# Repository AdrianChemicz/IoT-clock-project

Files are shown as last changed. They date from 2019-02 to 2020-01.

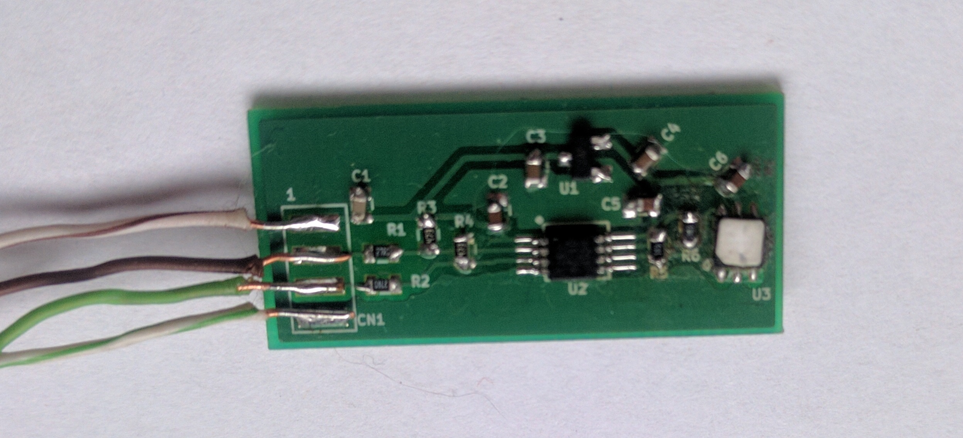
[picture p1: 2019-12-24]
clock_Pcb_schematic/clock_temperature_board/rev_1_0/clock_temperature_board_photo.jpg

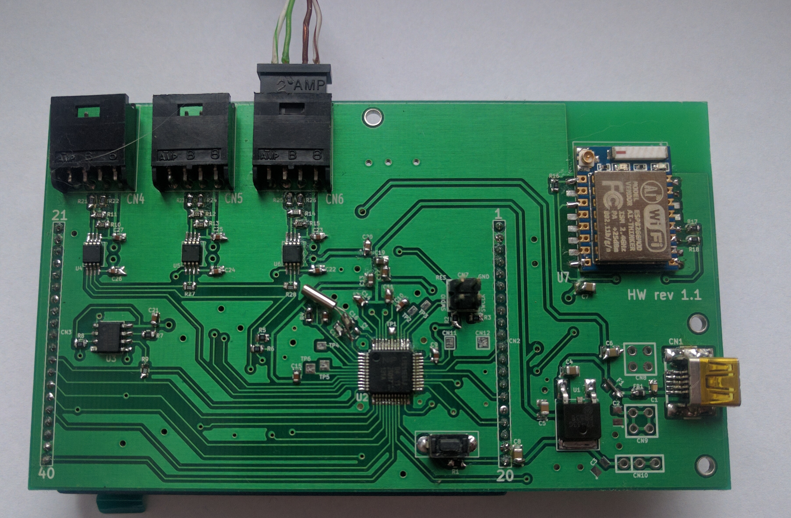
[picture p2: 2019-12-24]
clock_Pcb_schematic/clock_main_board/rev_1_1/clock_main_board_photo_bottom.jpg

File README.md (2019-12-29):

# IoT-clock-project
Concept:
Main idea behind project was create device which will gather 
temperature data from three sensors and display it on LCD. Selected
temperature source value will be stored in FRAM memory. 

Device will be used also as clock so near temperature on main 
window will be display curent hour. Device will be use WiFi 
interface to data synchronization(time and temperature measurement). 

Project phases:
1. I created PC driver which use FTDI chips and emulate interfaces of 
microntroller like GPIO, I2C, SPI and UART. I chosed LPC111X as target
microcontroller. I planed build final project on LPC1115 microcontroller.

2. Using emulated microcontroller interfaces I wrote drivers for LCD 
with ILI9325 controller, driver for touch screen with ADS7843 controller,
Si7021-A20 temperature sensor and ESP-01 module.

3) I created clock project with uGui library with first concept of 
application GUI. during development windows sdl library was used to 
display GUI. On final step of this phase test with real LCD was
performed and project work correctly.

4) I prepared code to run on real hardware (lpcxpresso board with 
LPC1114. Unfortunetly code exceed microcontroller flash limit. 
Code was modified to flash microcontroller and check basic 
functionality. After flashed all things work correctly. New 
microcontroller was chose to fulfil memory requirements it was 
LPC11E68. Evaluation board with this microcontroler was performed. 
Driver was ported to new microcontroller and all things work without
problem.

5) I prepared first release of clock board pcb with necessary
thing. Clock board contain FRAM (FM25W256), three I2C expander 
bus(PCA9507), footprint for ESP-07. The same code from my eval 
board run without any problem on clock board.

6) FRAM driver was added and store clockstate and temperature.
GUI functionality was added: set backlight of LCD, calibrate touch 
screen, factory reset, display temperature graph, calendar 
functionality, alarm animation. WiFi GUI concept was added.
uGui lobrary was modified to run faster.

First release of source code

7) WiFi support was be added. 

Second release of code.

8) New version of hardware with fixes.

9) Added support to monochrome bitmap in uGui. Added monochrome bitmap 
in GUI code. Added Options fields in bitmap.

Release of code with additional GUI thing.
First official release of HW.

10) Code refactoring is necessary to delete thing which isn't necessary 
and improve code readability.

Third release of code.

    -current place in project status-

11) Prepare housing for clock.
12) Prepare android application to control clock via Wifi.
13) Prepare document with clock specification.
14) Fix known issues:
	-change day should cause change data in time structure
	-fast switch between two temperature window cause issue with FRAM loading
	-load display temperature should load temperature even if gap will detected

License of code project:
  Below drivers is licensed under BSD 3-claus license:
  -BacklightControl
  -BuzzerControl
  -ESP_Layer
  -FRAM_Driver
  -GPIO_Driver
  -I2C_Driver
  -LCD
  -SOMEIP_Layer
  -SPI_Driver
  -TemperatureSensor
  -TouchPanel
  -UART_Driver
  
  Below files is licensed under GPL license:
  -ClockControl
  -GUI_Clock
  -Thread
  -WIFI_InteractionLayer

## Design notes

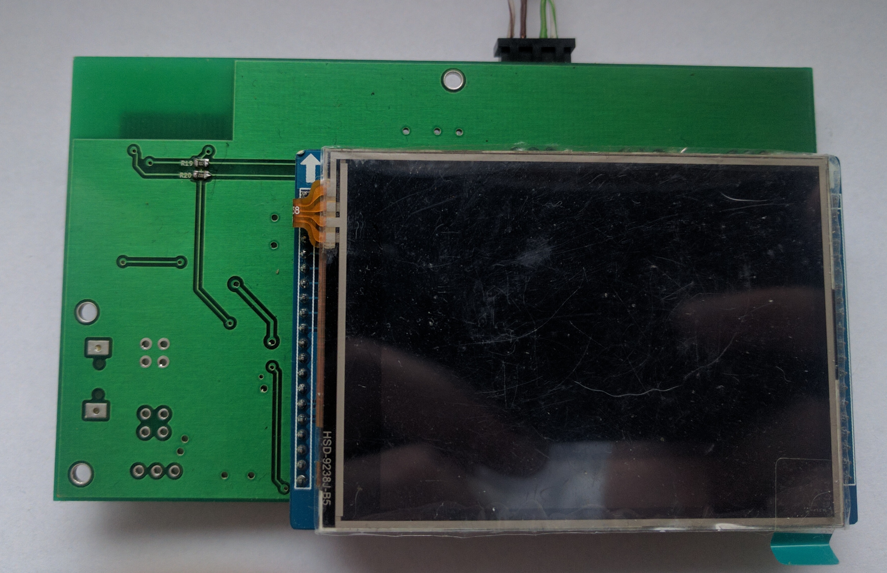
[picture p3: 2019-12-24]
clock_Pcb_schematic/clock_main_board/rev_1_1/clock_main_board_photo_upper.jpg

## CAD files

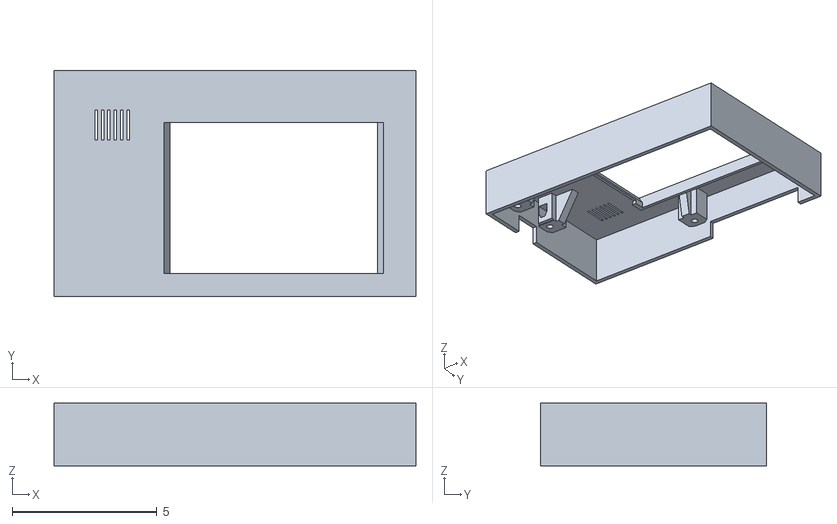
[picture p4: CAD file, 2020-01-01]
housing_stl_and_blender_files/ver_1_0/STL_Files/ClockHousing_UpperPart.stl
12.5 x 7.80 x 2.17

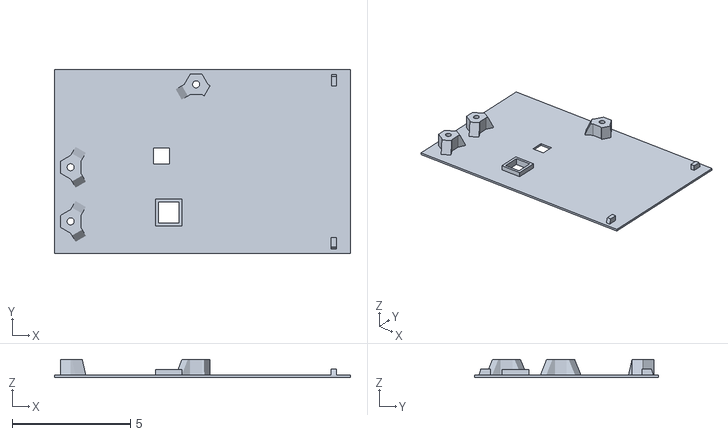
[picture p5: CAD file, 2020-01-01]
housing_stl_and_blender_files/ver_1_0/STL_Files/ClockHousing_BottomPart.stl
12.5 x 7.78 x 0.765

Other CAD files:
housing_stl_and_blender_files/ver_1_0/ClockHousing.blend
housing_stl_and_blender_files/ver_1_0/ClockHousing_AllStepsToCreate.blend
housing_stl_and_blender_files/ver_1_0/ClockHousing_BottomPart.blend
housing_stl_and_blender_files/ver_1_0/ClockHousing_UpperPart.blend
housing_stl_and_blender_files/ver_1_0/ClockPcb.blend
housing_stl_and_blender_files/ver_1_0/ClockPcb_AllStepsToCreate.blend

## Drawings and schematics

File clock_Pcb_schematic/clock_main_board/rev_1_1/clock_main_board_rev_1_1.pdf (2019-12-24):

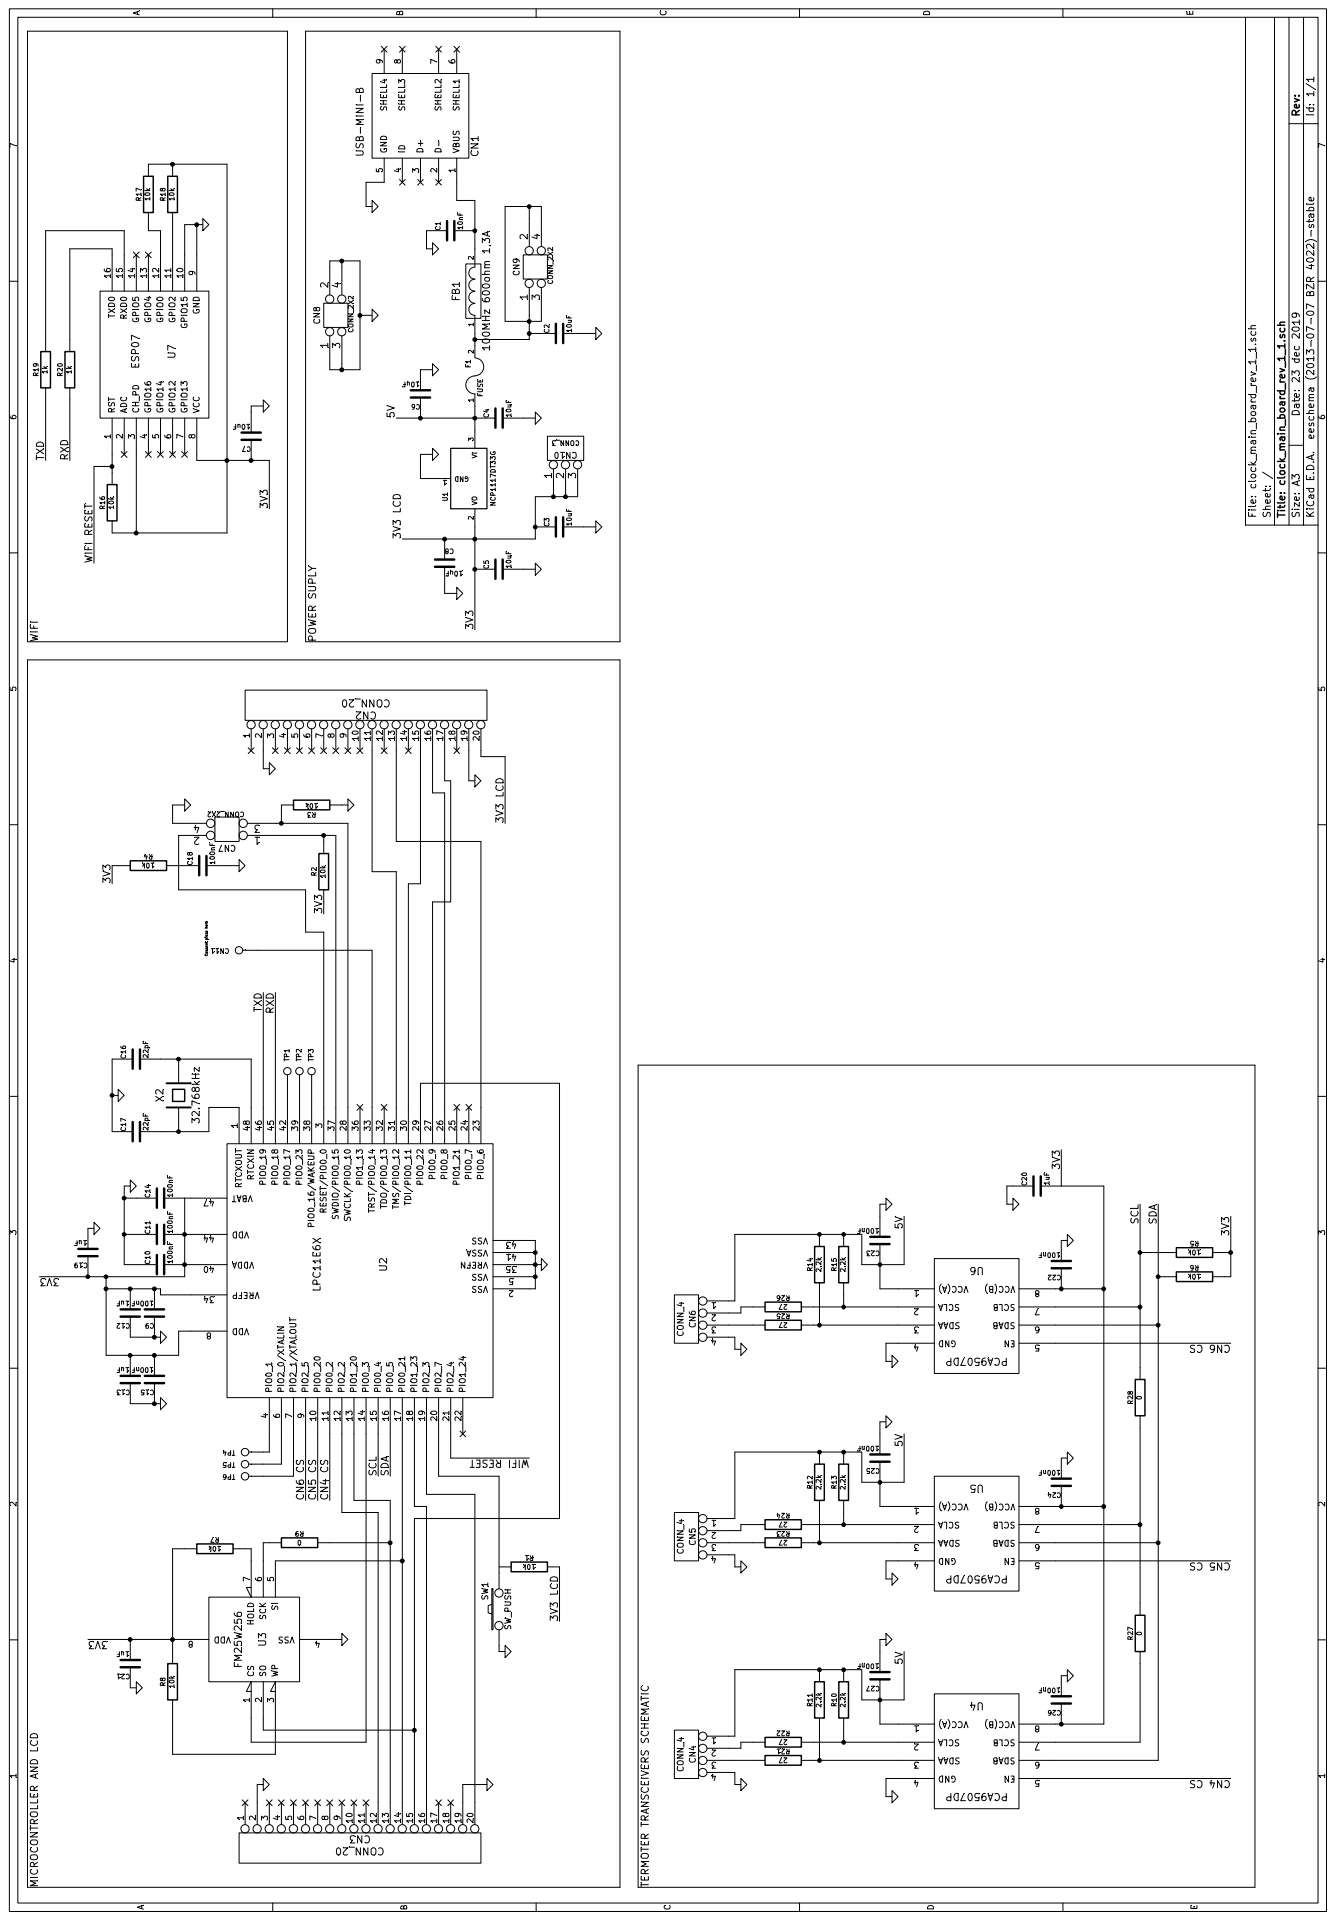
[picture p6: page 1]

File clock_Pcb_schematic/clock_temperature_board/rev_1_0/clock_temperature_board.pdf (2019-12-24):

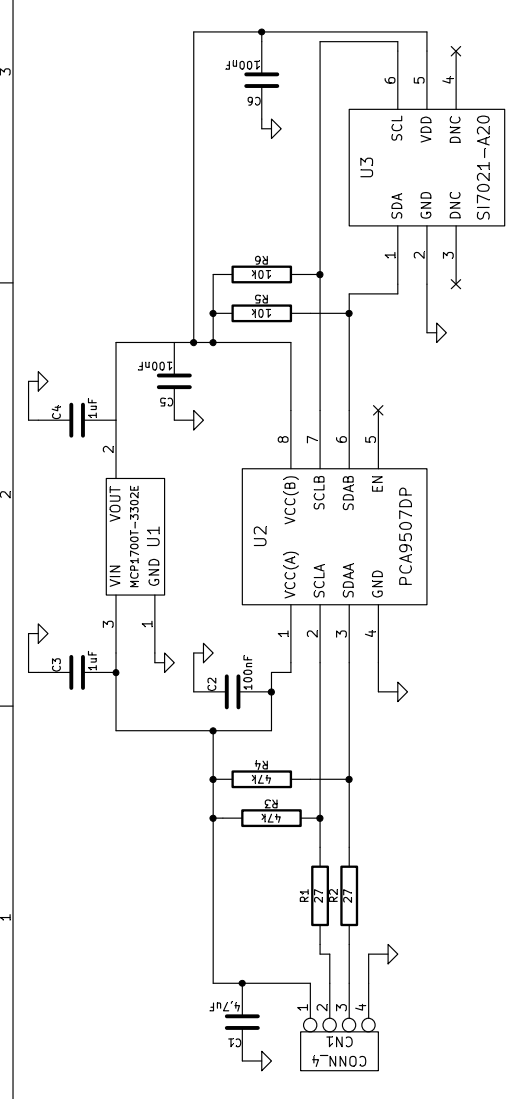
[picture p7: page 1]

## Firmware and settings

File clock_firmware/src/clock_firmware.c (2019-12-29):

/*

clock_firmware
Copyright (C) 2019 Adrian Chemicz

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
You should have received a copy of the GNU General Public License
along with this program. If not, see <http://www.gnu.org/licenses/>. */

#ifdef __USE_CMSIS
#include "chip.h"
#endif

#include "GPIO_Driver.h"
#include "SPI_Driver.h"
#include "UART_Driver.h"
#include "I2C_Driver.h"
#include "TouchPanel.h"
#include "GUI_Clock.h"
#include "TemperatureSensor.h"
#include "BacklightControl.h"
#include "BuzzerControl.h"
#include "FRAM_Driver.h"
#include "Thread.h"
#include "ClockControl.h"
#include "ESP_Layer.h"
#include "LCD.h"

#include <stdint.h>
#include <cr_section_macros.h>

int main(void)
{
	/**********************************
	*	initialize section
	***********************************/
	ClockChangeFrequency();

	//init touch mode
	TouchPanel_Init(1);

	//init GPIO port
	GPIO_Init();

	//init real LCD
	LCD_Init(0);

	FRAM_Init(1);

	//init backlight parameter
	Backlight_Init();

	Buzzer_Init();

	Chip_CRC_Init();

	//init bus for thermal sensors
	I2C_DriverInit(0);

	//init GPIO for manage I2C transceiver
	TemperatureSensor_Init();

	ESP_Init(0, 115200, 400, 3, 0);

	UART_DisableInterrupts(ESP_GetUartPortNumber());

	//search structure data in FRAM memory - two valid block is stored.
	if(ClockStateLoader(FRAM_CLOCK_STATE_FIRST_COPY))
	{

	}
	else if(ClockStateLoader(FRAM_CLOCK_STATE_SECOND_COPY))
	{

	}
	else//if all block is invalid then clear structure and init clock again
	{
		memset(&ClockState, 0, sizeof(ClockState));

		//set default brightness value
		ClockState.brightness = 80;

		//get calibration parameter for LCD
		ClockInitTouchScreen();

		//set default parameter for calendar - this parameter will be interpret as __ - __ - ____
		ClockState.day = INVALID_CALENDAR_DATE;
		ClockState.month = INVALID_CALENDAR_DATE;
		ClockState.year = INVALID_CALENDAR_DATE;

		//initialize FRAM index of all temperature sources
		ClockState.TemperatureSensorTable[INSIDE_TEMPERATURE].temperatureFramIndex = NOT_INITIALIZED_FRAM_INDEX_VALUE;
		ClockState.TemperatureSensorTable[OUTSIDE_TEMPERATURE].temperatureFramIndex = NOT_INITIALIZED_FRAM_INDEX_VALUE;
		ClockState.TemperatureSensorTable[FURNACE_TEMPERATURE].temperatureFramIndex = NOT_INITIALIZED_FRAM_INDEX_VALUE;
	}

	//set brightness
	Backlight_SetBrightness(ClockState.brightness);

	//calibrate LCD
	TouchPanel_SetCalibrationParameter(ClockState.x1RawCalibrationValue, ClockState.x2RawCalibrationValue,
		ClockState.y1RawCalibrationValue, ClockState.y2RawCalibrationValue);

	//clear fields which state must be checked again in new lifecycle
	ClockState.sharedSpiState = NOT_USED;
	ClockState.FramTransactionIdentifier = 0;

	//fields responsible for temperature
	ClockState.TemperatureSensorTable[INSIDE_TEMPERATURE].temperatureValue = INVALID_READ_SENSOR_VALUE;
	ClockState.TemperatureSensorTable[INSIDE_TEMPERATURE].temperatureValid = false;

	ClockState.TemperatureSensorTable[OUTSIDE_TEMPERATURE].temperatureValue = INVALID_READ_SENSOR_VALUE;
	ClockState.TemperatureSensorTable[OUTSIDE_TEMPERATURE].temperatureValid = false;

	ClockState.TemperatureSensorTable[FURNACE_TEMPERATURE].temperatureValue = INVALID_READ_SENSOR_VALUE;
	ClockState.TemperatureSensorTable[FURNACE_TEMPERATURE].temperatureValid = false;

	ClockState.refreshTemperatureValues = false;

	//clear fields responsible for raise allarm
	ClockState.firstAlarmRaised = false;
	ClockState.secondAlarmRaised = false;
	ClockState.temperatureFurnaceAlarmRaised = false;

	//clear counter responsible for refresh GUI interface if touch wasn't detected during 10s
	ClockState.refreshGuiCounter = 0;

	ClockState.factoryResetViaGui = false;

	//clear WiFi flags and IP address
	ClockState.wifiReady = false;
	ClockState.wifiApnReceived = false;
	ClockState.wifiConnected = false;
	ClockState.wifiStartDisconnect = false;

	memset(ClockState.ipAddressAssignedToDevice, 0, IP_ADDRESS_BYTE_LENGTH);

	//init structures responsible for draw temperature
	for(int i = 0; i < READ_TEMP_FRAM_BUFFER_SIZE; i++)
	{
		ReadFramTempBufferTable[i].availabilityFlag = false;
		ReadFramTempBufferTable[i].framIndex = 0;
		ReadFramTempBufferTable[i].notExistFlag = false;

		if(i == (READ_TEMP_FRAM_BUFFER_SIZE - 1))
		{
			ReadFramTempBufferTable[i].pointerToNextElement = &ReadFramTempBufferTable[0];
			ReadFramTempBufferTable[i].pointerToPreviousElement = &ReadFramTempBufferTable[i - 1];
		}
		else if(i == 0)
		{
			ReadFramTempBufferTable[i].pointerToNextElement = &ReadFramTempBufferTable[i + 1];
			ReadFramTempBufferTable[i].pointerToPreviousElement = &ReadFramTempBufferTable[(READ_TEMP_FRAM_BUFFER_SIZE-1)];
		}
		else
		{
			ReadFramTempBufferTable[i].pointerToNextElement = &ReadFramTempBufferTable[i + 1];
			ReadFramTempBufferTable[i].pointerToPreviousElement = &ReadFramTempBufferTable[i - 1];
		}
	}

	GUI_ClockInit();

	Thread_Init();

	ClockInitRtc();

	/**********************************
	*	main loop
	***********************************/
	for(;;)
	{
		static bool touchPanelState = false;

		if(TouchPanel_Process())
		{
			touchPanelState = true;
			uint16_t xPixelPosition = TouchPanel_CalculatePixelX(TouchPanel_ReturnRawX());
			uint16_t yPixelPosition = TouchPanel_CalculatePixelY(TouchPanel_ReturnRawY());

#if 1		//draw point after touch for debug purpose
			UG_DrawFrame(xPixelPosition - 2, yPixelPosition - 2, xPixelPosition + 2, yPixelPosition + 2, 0);
#endif
			UG_TouchUpdate(TouchPanel_CalculatePixelX(TouchPanel_ReturnRawX()),
				TouchPanel_CalculatePixelY(TouchPanel_ReturnRawY()), TOUCH_STATE_PRESSED);

			GUI_UpdateTime();
			UG_Update();

			ClockState.refreshGuiCounter = 0;
		}

		if(touchPanelState && !TouchPanel_TouchState())
		{
			UG_TouchUpdate(-1, -1, TOUCH_STATE_RELEASED);
			UG_Update();
			UG_Update();
			touchPanelState = false;

			ClockState.refreshGuiCounter = 0;
		}

		if(ClockState.refreshTemperatureValues == REFRESH)
		{
			GUI_UpdateTemperature();
			ClockState.refreshTemperatureValues = REFRESH_PERFORMED;
		}

		if(ClockState.refreshGuiCounter >= 5*ONE_SECONDS)
		{
			GUI_UpdateTime();

			UG_Update();
			ClockState.refreshGuiCounter = 0;
		}

		GUI_ProcessTemperatureWindow();
		GUI_ProcessAlarmAnimation();
		GUI_RefreshWifiWindow();
	}/* for(;;) */

    return 0;
}

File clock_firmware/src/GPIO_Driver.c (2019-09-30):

/*
 * Copyright (c) 2018, 2019, Adrian Chemicz
 * All rights reserved.
 *
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
 * THIS SOFTWARE IS PROVIDED BY THE COPYRIGHT HOLDERS AND CONTRIBUTORS "AS IS" AND
 * ANY EXPRESS OR IMPLIED WARRANTIES, INCLUDING, BUT NOT LIMITED TO, THE IMPLIED
 * WARRANTIES OF MERCHANTABILITY AND FITNESS FOR A PARTICULAR PURPOSE ARE
 * DISCLAIMED. IN NO EVENT SHALL COPYRIGHT HOLDER BE LIABLE FOR ANY
 * DIRECT, INDIRECT, INCIDENTAL, SPECIAL, EXEMPLARY, OR CONSEQUENTIAL DAMAGES
 * (INCLUDING, BUT NOT LIMITED TO, PROCUREMENT OF SUBSTITUTE GOODS OR SERVICES;
 * LOSS OF USE, DATA, OR PROFITS; OR BUSINESS INTERRUPTION) HOWEVER CAUSED AND
 * ON ANY THEORY OF LIABILITY, WHETHER IN CONTRACT, STRICT LIABILITY, OR TORT
 * (INCLUDING NEGLIGENCE OR OTHERWISE) ARISING IN ANY WAY OUT OF THE USE OF THIS
 * SOFTWARE, EVEN IF ADVISED OF THE POSSIBILITY OF SUCH DAMAGE.
 */

#include "GPIO_Driver.h"

#if USE_LPC111x_SERIES
#include "LPC11xx.h"
#endif

#if USE_LPC11E6x_SERIES
#include "chip.h"
#endif

static uint32_t* GPIO_GetBaseAddress(uint8_t portNumber)
{
	uint32_t* basePointer = 0;
#if USE_LPC111x_SERIES
	switch(portNumber)
	{
	case 0:
		basePointer = (uint32_t*)LPC_GPIO0;
		break;
	case 1:
		basePointer = (uint32_t*)LPC_GPIO1;
		break;
	case 2:
		basePointer = (uint32_t*)LPC_GPIO2;
		break;
	case 3:
		basePointer = (uint32_t*)LPC_GPIO3;
		break;
	default:
		basePointer = 0;
		break;
	}
#endif

#if USE_LPC11E6x_SERIES
	return basePointer;
#endif
}

void GPIO_Init(void)
{
	//Defined by user
	//turn on options responsible for change GPIO purpose like UART, ADC or SPI
	LPC_SYSCON->SYSAHBCLKCTRL |= (1<<16);
	//LCD CS - PIO0_12
	LPC_IOCON->PIO0[12] = 1;
	//LCD_Reset - PIO0_11
	LPC_IOCON->PIO0[11] = 1;

	//TP3(Debug purpose) PIO0_16
	GPIO_Direction(0, 16, GPIO_DIR_OUTPUT);
}

void GPIO_Direction(uint8_t port, uint8_t pin, GPIO_DIRECTION dir)
{
#if USE_LPC111x_SERIES
	uint32_t tmpDir = LPC_GPIO0->DIR;
	uint32_t dirMask = ~(1<<pin);
	LPC_GPIO_TypeDef *GPIO_Port = (LPC_GPIO_TypeDef*)GPIO_GetBaseAddress(port);

	GPIO_Port->DIR = (tmpDir & dirMask)|(dir<<pin);
#endif

#if USE_LPC11E6x_SERIES
	uint32_t tmpDir = LPC_GPIO->DIR[port];
	uint32_t dirMask = ~(1<<pin);

	LPC_GPIO->DIR[port] = (tmpDir & dirMask)|(dir<<pin);
#endif
}

void GPIO_SetState(uint8_t port, uint8_t pin, bool state)
{
#if USE_LPC111x_SERIES
	LPC_GPIO_TypeDef *GPIO_Port = (LPC_GPIO_TypeDef*)GPIO_GetBaseAddress(port);
	GPIO_Port->MASKED_ACCESS[1<<pin] = (state<<pin);
#endif

#if USE_LPC11E6x_SERIES
	LPC_GPIO->B[port][pin] = state;
#endif
}

bool GPIO_GetState(uint8_t port, uint8_t pin)
{	
#if USE_LPC111x_SERIES
	LPC_GPIO_TypeDef *GPIO_Port = (LPC_GPIO_TypeDef*)GPIO_GetBaseAddress(port);
	return ((GPIO_Port->MASKED_ACCESS[1<<pin])>>pin);
#endif

#if USE_LPC11E6x_SERIES
	return LPC_GPIO->B[port][pin];
#endif
}

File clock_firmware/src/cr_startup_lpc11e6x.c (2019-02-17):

//*****************************************************************************
// LPC11E6x Microcontroller Startup code for use with LPCXpresso IDE
//
// Version : 140113
//*****************************************************************************
//
// Copyright(C) NXP Semiconductors, 2014
// All rights reserved.
//
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
// Permission to use, copy, modify, and distribute this software and its
// documentation is hereby granted, under NXP Semiconductors' and its
// licensor's relevant copyrights in the software, without fee, provided that it
// is used in conjunction with NXP Semiconductors microcontrollers.  This
// copyright, permission, and disclaimer notice must appear in all copies of
// this code.
//*****************************************************************************

#if defined (__cplusplus)
#ifdef __REDLIB__
#error Redlib does not support C++
#else
//*****************************************************************************
//
// The entry point for the C++ library startup
//
//*****************************************************************************
extern "C" {
    extern void __libc_init_array(void);
}
#endif
#endif

#define WEAK __attribute__ ((weak))
#define ALIAS(f) __attribute__ ((weak, alias (#f)))

//*****************************************************************************
#if defined (__cplusplus)
extern "C" {
#endif

//*****************************************************************************
#if defined (__USE_CMSIS) || defined (__USE_LPCOPEN)
// Declaration of external SystemInit function
extern void SystemInit(void);
#endif

// Patch the AEABI integer divide functions to use MCU's romdivide library
#ifdef __USE_ROMDIVIDE
// Location in memory that holds the address of the ROM Driver table
#define PTR_ROM_DRIVER_TABLE ((unsigned int *)(0x1FFF1FF8))
// Variables to store addresses of idiv and udiv functions within MCU ROM
unsigned int *pDivRom_idiv;
unsigned int *pDivRom_uidiv;
#endif

//*****************************************************************************
//
// Forward declaration of the default handlers. These are aliased.
// When the application defines a handler (with the same name), this will 
// automatically take precedence over these weak definitions
//
//*****************************************************************************
     void ResetISR(void);
WEAK void NMI_Handler(void);
WEAK void HardFault_Handler(void);
WEAK void SVC_Handler(void);
WEAK void PendSV_Handler(void);
WEAK void SysTick_Handler(void);
WEAK void IntDefaultHandler(void);
//*****************************************************************************
//
// Forward declaration of the specific IRQ handlers. These are aliased
// to the IntDefaultHandler, which is a 'forever' loop. When the application
// defines a handler (with the same name), this will automatically take
// precedence over these weak definitions
//
//*****************************************************************************
void PIN_INT0_IRQHandler (void) ALIAS(IntDefaultHandler);
void PIN_INT1_IRQHandler (void) ALIAS(IntDefaultHandler);
void PIN_INT2_IRQHandler (void) ALIAS(IntDefaultHandler);
void PIN_INT3_IRQHandler (void) ALIAS(IntDefaultHandler);
void PIN_INT4_IRQHandler (void) ALIAS(IntDefaultHandler);
void PIN_INT5_IRQHandler (void) ALIAS(IntDefaultHandler);
void PIN_INT6_IRQHandler (void) ALIAS(IntDefaultHandler);
void PIN_INT7_IRQHandler (void) ALIAS(IntDefaultHandler);
void GINT0_IRQHandler (void) ALIAS(IntDefaultHandler);
void GINT1_IRQHandler (void) ALIAS(IntDefaultHandler);
void I2C1_IRQHandler (void) ALIAS(IntDefaultHandler);
void USART1_4_IRQHandler (void) ALIAS(IntDefaultHandler);
void USART2_3_IRQHandler (void) ALIAS(IntDefaultHandler);
void SCT0_1_IRQHandler (void) ALIAS(IntDefaultHandler);
void SSP1_IRQHandler (void) ALIAS(IntDefaultHandler);
void I2C0_IRQHandler (void) ALIAS(IntDefaultHandler);
void TIMER16_0_IRQHandler (void) ALIAS(IntDefaultHandler);
void TIMER16_1_IRQHandler (void) ALIAS(IntDefaultHandler);
void TIMER32_0_IRQHandler (void) ALIAS(IntDefaultHandler);
void TIMER32_1_IRQHandler (void) ALIAS(IntDefaultHandler);
void SSP0_IRQHandler (void) ALIAS(IntDefaultHandler);
void USART0_IRQHandler (void) ALIAS(IntDefaultHandler);
void ADCA_IRQHandler (void) ALIAS(IntDefaultHandler);
void RTC_IRQHandler (void) ALIAS(IntDefaultHandler);
void BOD_WDT_IRQHandler (void) ALIAS(IntDefaultHandler);
void FMC_IRQHandler (void) ALIAS(IntDefaultHandler);
void DMA_IRQHandler (void) ALIAS(IntDefaultHandler);
void ADCB_IRQHandler (void) ALIAS(IntDefaultHandler);
void USBWakeup_IRQHandler (void) ALIAS(IntDefaultHandler);

//*****************************************************************************
// The entry point for the application.
// __main() is the entry point for redlib based applications
// main() is the entry point for newlib based applications
//*****************************************************************************
#if defined (__REDLIB__)
extern void __main(void);
#endif
extern int main(void);
//*****************************************************************************
//
// External declaration for the pointer to the stack top from the Linker Script
//
//*****************************************************************************
extern void _vStackTop(void);
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

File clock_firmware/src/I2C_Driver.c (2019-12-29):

/*
 * Copyright (c) 2018, 2019, Adrian Chemicz
 * All rights reserved.
 *
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
 * THIS SOFTWARE IS PROVIDED BY THE COPYRIGHT HOLDERS AND CONTRIBUTORS "AS IS" AND
 * ANY EXPRESS OR IMPLIED WARRANTIES, INCLUDING, BUT NOT LIMITED TO, THE IMPLIED
 * WARRANTIES OF MERCHANTABILITY AND FITNESS FOR A PARTICULAR PURPOSE ARE
 * DISCLAIMED. IN NO EVENT SHALL COPYRIGHT HOLDER BE LIABLE FOR ANY
 * DIRECT, INDIRECT, INCIDENTAL, SPECIAL, EXEMPLARY, OR CONSEQUENTIAL DAMAGES
 * (INCLUDING, BUT NOT LIMITED TO, PROCUREMENT OF SUBSTITUTE GOODS OR SERVICES;
 * LOSS OF USE, DATA, OR PROFITS; OR BUSINESS INTERRUPTION) HOWEVER CAUSED AND
 * ON ANY THEORY OF LIABILITY, WHETHER IN CONTRACT, STRICT LIABILITY, OR TORT
 * (INCLUDING NEGLIGENCE OR OTHERWISE) ARISING IN ANY WAY OUT OF THE USE OF THIS
 * SOFTWARE, EVEN IF ADVISED OF THE POSSIBILITY OF SUCH DAMAGE.
 */

#include "I2C_Driver.h"
#include "chip.h"

static uint16_t SCLL;
static uint16_t SCLH;

I2C_Device_Instance I2C_Device_Instance_Table[NUMBER_OF_I2C_PERIPHERALS];

static uint32_t* I2C_GetBaseAddress(uint8_t portNumber)
{
	uint32_t* basePointer = 0;
	switch(portNumber)
	{
	case 0:
		basePointer = (uint32_t*)LPC_I2C0;
		break;
	default:
		basePointer = 0;
		break;
	}

	return basePointer;
}

static void I2C_SetClockPrescalers(uint8_t portNumber)
{
	/*must be defined by user*/
	switch(portNumber)
	{
	case 0:
#if 0
		SCLL = 0x40;
		SCLH = 0x40;
#else
		SCLL = 0x80;
		SCLH = 0x80;
#endif

		break;
	default:
		SCLL = 0x40;
		SCLH = 0x40;
		break;
	}
}

void I2C_InterruptProccess(uint8_t portNumber)
{
	LPC_I2C_T *I2C_Port = (LPC_I2C_T*)I2C_GetBaseAddress(portNumber);
	uint8_t busStatus = I2C_Port->STAT;

	switch(busStatus)
	{
	case 0x08://call when start was send
		//change device status
		I2C_Device_Instance_Table[portNumber].deviceStatus = I2C_SENDING;
		//clear start bit (STAC - START flag Clear bit)
		I2C_Port->CONCLR = (1<<5);

		if(I2C_Device_Instance_Table[portNumber].dataToSend > 0)
		{
			I2C_Device_Instance_Table[portNumber].dataToSendStatus = 0;
			I2C_Port->DAT = I2C_Device_Instance_Table[portNumber].deviceAddress;
		}
		else if(I2C_Device_Instance_Table[portNumber].dataToRead > 0)
		{
			I2C_Device_Instance_Table[portNumber].dataToReadStatus = 0;
			I2C_Port->DAT = (I2C_Device_Instance_Table[portNumber].deviceAddress|1U);
		}

		break;

	case 0x10://call when repeated start was send
		//clear start bit (STAC - START flag Clear bit)
		I2C_Port->CONCLR = (1<<5);

		I2C_Device_Instance_Table[portNumber].dataToReadStatus = 0;
		I2C_Port->DAT = (I2C_Device_Instance_Table[portNumber].deviceAddress|1U);
		break;
	//send data
	case 0x18://call when device address was send and ACK was received
	case 0x20://call when device address was send and ACK wasn't received
	case 0x28://call when data was send and ACK was received
	case 0x30://call when data was send and ACK wasn't received
		//execute when all data was send
		if(I2C_Device_Instance_Table[portNumber].dataToSendStatus
				== I2C_Device_Instance_Table[portNumber].dataToSend)
		{
			//check read buffer
			if(I2C_Device_Instance_Table[portNumber].dataToRead > 0)
			{
				//send start bit (in control set register STA bit - START flag)
				I2C_Port->CONSET = (1<<5);
			}
			else//execute when read data isn't necessary
			{
				//send stop bit(set STO bit - STOP flag.)
				I2C_Port->CONSET = (1<<4);
				I2C_Device_Instance_Table[portNumber].deviceStatus = I2C_WAITING_FOR_DATA;
			}
		}
		else //send data
		{
			I2C_Port->DAT = I2C_Device_Instance_Table[portNumber].sendBuffer[I2C_Device_Instance_Table[portNumber].dataToSendStatus];
			I2C_Device_Instance_Table[portNumber].dataToSendStatus++;
		}
		break;

	case 0x40://call when address of device was send with ACK
	case 0x48://call when address of device was send without ACK
		//check how much read data is needed. If one then clear ACK bit
		if((I2C_Device_Instance_Table[portNumber].dataToRead - I2C_Device_Instance_Table[portNumber].dataToReadStatus) == 1)
			//in control clear register set AAC - Assert acknowledge Clear bit
			I2C_Port->CONCLR = (1<<2);
		else//then more than one then set ACK bit
			//in control set register set AA - Assert acknowledge flag
			I2C_Port->CONSET = (1<<2);
		break;

	case 0x50://data was received. ACK was returned
		//check how much read data is needed. If one then clear ACK bit
		if((I2C_Device_Instance_Table[portNumber].dataToRead - I2C_Device_Instance_Table[portNumber].dataToReadStatus - 1) == 1)
			//in control clear register set AAC - Assert acknowledge Clear bit
			I2C_Port->CONCLR = (1<<2);
		else//then more than one then set ACK bit
			//in control set register set AA - Assert acknowledge flag
			I2C_Port->CONSET = (1<<2);

		I2C_Device_Instance_Table[portNumber].readBuffer[I2C_Device_Instance_Table[portNumber].dataToReadStatus] = I2C_Port->DAT;
		I2C_Device_Instance_Table[portNumber].dataToReadStatus++;
		break;

	case 0x58://data was received and ACK wasn't returned
		I2C_Device_Instance_Table[portNumber].readBuffer[I2C_Device_Instance_Table[portNumber].dataToReadStatus] = I2C_Port->DAT;
		I2C_Device_Instance_Table[portNumber].dataToReadStatus++;
		//in control set register set STOP flag
		I2C_Port->CONSET = (1<<4);

		I2C_Device_Instance_Table[portNumber].deviceStatus = I2C_WAITING_FOR_DATA;
		break;
	}
	//clear interrupt bit (SIC - I2C interrupt Clear bit)
	I2C_Port->CONCLR = (1<<3);
}

void I2C0_IRQHandler()
{
	I2C_InterruptProccess((uint8_t)0);
}

void I2C_DriverInit(uint8_t portNumber)
{
	LPC_I2C_T *I2C_Port = (LPC_I2C_T*)I2C_GetBaseAddress(portNumber);
	I2C_SetClockPrescalers(portNumber);

	I2C_Device_Instance_Table[portNumber].deviceStatus = I2C_WAITING_FOR_DATA;
	//turn on options responsible for change GPIO purpose like UART, ADC or SPI
	LPC_SYSCON->SYSAHBCLKCTRL |= (1<<16);

	if(portNumber == 0)
	{
		//I2C reset
		LPC_SYSCON->PRESETCTRL |= 2;
		//connect I2C to AHB bus
		LPC_SYSCON->SYSAHBCLKCTRL |= (1<<5);

		//configure GPIO pin which is used by I2C
		//SCL
		LPC_IOCON->PIO0[4] |= 1;
		//SDA
		LPC_IOCON->PIO0[5] |= 1;
	}

	//clear all bit inside Control Clear register
	I2C_Port->CONCLR = 0x6C;
	//configure presscaller
	I2C_Port->SCLL = SCLL;
	I2C_Port->SCLH = SCLH;

	if(portNumber == 0)
	{
		//enable I2C interrupt
		NVIC_EnableIRQ(I2C0_IRQn);
	}
	//set bit responsible for enable interface(I2EN - I2C interface enable)
	I2C_Port->CONSET = (1<<6);
}
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

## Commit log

2019-01-06 Add highier level driver(header files)
2019-01-06 Add highier level driver(c files)
2019-01-13 Added low level drivers for SPI, UART, GPIO
2019-01-13 add low level driver I2C(header files)
2019-01-13 add low level driver I2C(source file)
2019-12-24 Add clock temperature board data
    In this commit was added:
    -Kicad files with pcb and schematic
    -gerber files which was send to factory
    -pdf file with schematic
    -photo with prepared board
    [clock_temperature_board.kicad_pcb, clock_temperature_board.sch]
2019-12-24 add pcb a schematic of clock main board
    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
    [clock_main_board_rev_1_1.kicad_pcb, clock_main_board_rev_1_1.sch]
2019-12-29 Third release of code with refactoring and improvements
    -change in few places enums styles
    -change few defines to enums
    -move all code to lock SPI to single function(delete duplicated code)
    -faster refresh temperature and load data on startup faster
    -in file Thread.c and GUI_Clock.h more comment to function and structure was added
2020-01-01 First version of clock housing
    -blender file with PCB(only important element is added) and file with all steps used to create final model
    -blender file with housing and file with all steps used to create final model
    -blender files with separate elements
    -stl files with upper and bottom element of housing
    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
    [ClockHousing.blend, ClockHousing_AllStepsToCreate.blend, ClockHousing_BottomPart.blend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]

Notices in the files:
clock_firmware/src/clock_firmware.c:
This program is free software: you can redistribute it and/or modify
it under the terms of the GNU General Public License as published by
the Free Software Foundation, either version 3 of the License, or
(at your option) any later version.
